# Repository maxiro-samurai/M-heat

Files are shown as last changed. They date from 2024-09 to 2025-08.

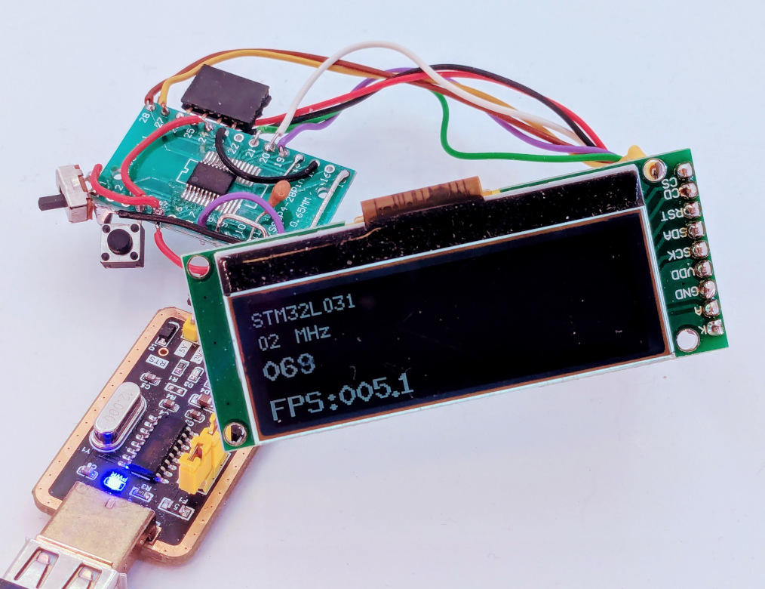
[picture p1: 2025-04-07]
Software/esp32/components/u8g2/sys/arm/stm32l031x4/u8g2_dma_spi_2mhz/stm32l031_wired.jpg

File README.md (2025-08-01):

# M-heat 迷你加热台项目

焊接电路使用电烙铁太麻烦了，尤其遇到0402、QFN这种封装的很难受，想做一个加热板并且还要够mini。本次项目主要参考了 

* 找羊大佬 [加热台量产计划](https://oshwhub.com/sheep_finder/pcb-heng-wen-jia-re-tai)

* 小O和小Q [[PD协议 | 高颜值]mini加热台](https://oshwhub.com/littleoandlittleq/bian-xie-jia-re-tai)

* 稚晖君 [OpenHeat] (https://github.com/peng-zhihui/OpenHeat)

# 项目介绍

主要结构部分采用mini加热台整体框架，外壳自己重新设计。OLED屏幕换成更大一点的128*64，主控芯片采用ESP32，不使用外接电源只需要一根TYPE-C，功率为65W。UI界面使用[oled-ui-astra-lite](https://github.com/AstraThreshold/oled-ui-astra-lite)，感谢无理造物大佬开源，这位大佬的项目也很有意思。

使用编码器与thingsboard来控制加热台，可以实现温度设定、PID参数整定、监测加热器状态等功能，最高温度250°，符合一般中低温锡膏使用情形。源项目中还有初次上电温度校准功能，目前并未添加。

## 未加外壳




## 整体装配
control_board-v20


## 加热板
加热板使用希尔伯特曲线填充， 希尔伯特曲线是一种能在 2D平面完美填充正方形的曲线，连续且稳定（当细分足够小时，线构成面）而又不可导的曲线。只要恰当选择函数，画出一条连续的参数曲线，当参数 t 在 [0、1 ] 区间取值时，曲线将遍历单位正方形中所有的点，得到一条充满空间的曲线。

阻值计算公式为：$R = \frac{\rho L}{1000W \cdot D}$

ρ为铜的电阻率：ρ=0.0175 $\frac{\Omega\cdot mm^2}{m}$

L为走线长度：单位(m)

W为走线宽度：单位(m)

D为PCB铜厚度：1oz 覆铜板铜箔的厚度是0.035mm

取 L=0.4mm（即单位长度），W=0.2mm，可以估算Hilbert 曲线在不同阶数下等效的PCB电阻。
本设计中导线电阻约等于6.67 Ω。

加热板使用铝基板打样


## PID参数整定

P值与I值尽量不要太大，这个版本没有风扇，所以降温比较慢，P值和I值过大会导致超调很多并且很慢恢复。

# 开发记录
* 2024/9/12   目前正在打板验证，本次提交是创建项目仓库。

* 2024/9/14   电源部分设计有问题，DC-DC降压模块稳定工作需要一定压降，TPS5430和MP1584EN输入5V输出必须比5V低。准备更改电源方案，输入转3.3V，3.3V再升压得到5V。

* 2024/11/19  近期在完善打印机，准备加快速度完成本项目，之前电路已经更改暂时未打板验证。

* 2024/12/3   更改电路踩坑记录: 1.type-c母座不要虚焊，cc1 cc2引脚可以不用下拉电阻，ch224k芯片内部已经内置下拉5.1K电阻。2.ch224k芯片背部GND焊盘一定要焊上，不然诱导不出来20V电压。3.充电器一定要用带支持PD20V协议的，一开始诱导不出来后面换了个充电头就可以诱导出来了。4.LM358引脚一定要看好，在找羊原项目里按照原理图画的8脚跟4脚搞反了，8脚是电源正。5.ESP32下载电路有问题，插上type-c后电脑可以识别CH340芯片，用示波器看EN跟BOOT0引脚也有跳变，就是波形可能不符合上电顺序导致无法进入下载程序模式，参考别人设计后发现他们en引脚都上拉电阻并且连了一个电容做延时，所以电路还需要继续完善。6.蜂鸣器封装需要更换。

* 2025/4/14   快开始找工作了，加快项目进度，之前电路修改部分已完成。软件部分把UI、蜂鸣器、编码器、已经移植。目前正在调试ADC测温电路，没有搞清原项目中的测温原理。

    
原理：分高温和低温，因为高温NTC电阻测温精度较差，低温精度还行。低温直接使用，高温下对电压放大21倍后使用线性插值方法对误差进行补偿。

* 2025/4/22   想到后面调PID每次都需要重新下载烧录代码很麻烦，所以想到用野火的串口助手，里面有调试PID的功能。但是需要满足野火通信的协议，参考[踏雪Vernon](https://github.com/taxue-vernon/firetool_PID_driver_esp)大佬的代码把功能移植到本项目中。当前面临问题：只有串口0能用，串口0还是下载程序的串口，软件把下载串口占用导致无法下载程序，我在改进后的板子上在EN引脚上添加了一个复位按键，理论上来说可以下载程序。担心是多余的，自动下载电路中有硬件流控，能使ESP32自动复位进入bootloader。软件部分还需要增加保存PID、温度、时间等一些温度的设置功能，这就需要非易失存储器保存数据，比如eeprom。这里使用ESP32中的NVS来存储，详情看[ESP32 非易失性存储器NVS](https://docs.espressif.com/projects/esp-idf/zh_CN/v5.4.1/esp32s3/api-reference/storage/nvs_flash.html#id2)。还忽略了一点，如果使用野火串口助手则无法开启加热功能，因为电脑端USB口无法输出65W。最终调试PID还是没用到串口助手，而是使用WIFI网页控制进行调试，如果想使用串口可以多引出一个串口1用来调试。

* 2025/5/14   使用[thingsboard](https://github.com/thingsboard/thingsboard)开源物联网框架搭建服务器，实现在网页端显示温度，PID参数并且对设备进行控制。

    

* 2025/5/23  基本功能已经开发完毕，后续还需添加蓝牙通信功能（使用手机进行控制）、更完善的加热状态判断。结构后续也可完善，在200°温度下，由顶针连接控制板导致控制板温度也很高，这个问题在原mini加热台项目中应该也存在，3D打印的外壳与加热板离得很近，长时间使用可能会有问题。加热板也可做沉孔，目前版本中并未做沉孔。

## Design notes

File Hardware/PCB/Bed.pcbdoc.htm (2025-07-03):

Reporting Options

# File in Newer Format

Date | : | 2025/7/3
Time | : | 9:25:11
Filename | : | D:\project\M-heat\Hardware\PCB\Bed.pcbdoc

Version | Warning
6.3 | CAUTION - Via connections to both hatched and solid signal layer polygons are now controlled by the polygon connect style rule. Re-pouring polygons may result in physical copper differences.
Summer 09 | CAUTION - File contains old violation objects. These violations are no longer supported & will not be loaded. Please run DRC after opening this file in order to refresh the violations.
Summer 09 | CAUTION - Existing testpoint rules and settings are used as fabrication testpoint information.
Release 12 | CAUTION - Air Gap Width previously controlled by Clearance rule is now controlled by Polygon Connect Style rule's newly introduced Air Gap Width (set to default value). Suggest reviewing each Polygon Connect Style rule's Air Gap Width attribute for correctness.
Release 13 | CAUTION - Silkscreen Over Component Pads Rules are converted to Silk To Solder Mask Clearance Rules. Suggest examining rule scopes for accuracy.

This file was generated by an earlier version of the software

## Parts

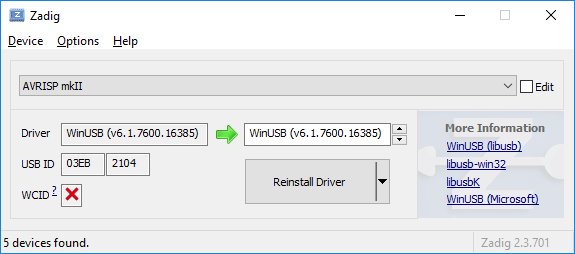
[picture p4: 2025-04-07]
Software/esp32/components/u8g2/sys/avr/as7/as7_011.png

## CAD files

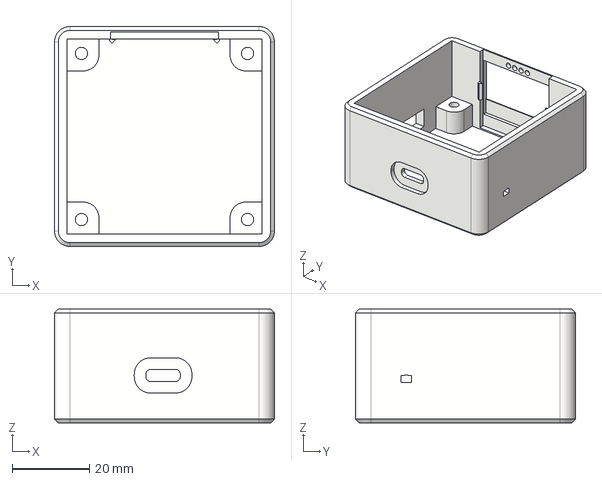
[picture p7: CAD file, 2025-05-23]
Hardware/3DFile/外壳.step
57.0 x 57.0 x 29.5 mm

Software/esp32/components/u8g2/sys/arduino/u8g2_full_buffer/SwitchBox/board.dxf
60
40
52
8
24
80
30
32
25
100
190
4
12
6
14

Software/esp32/components/u8g2/sys/arm/stm32l031x6/clock.dxf
65
32
28
16
Draufsicht
Vorderansicht
von unten
von rechts
von links
14
6
45
60
30
20
8
35
75
55
10
12

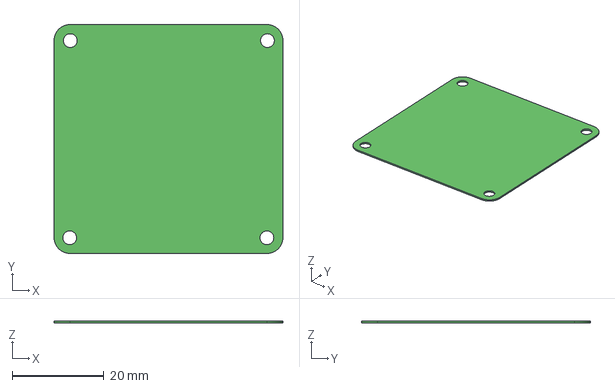
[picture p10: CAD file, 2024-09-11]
Hardware/3DFile/Bed.step
50.0 x 50.0 x 0.411 mm

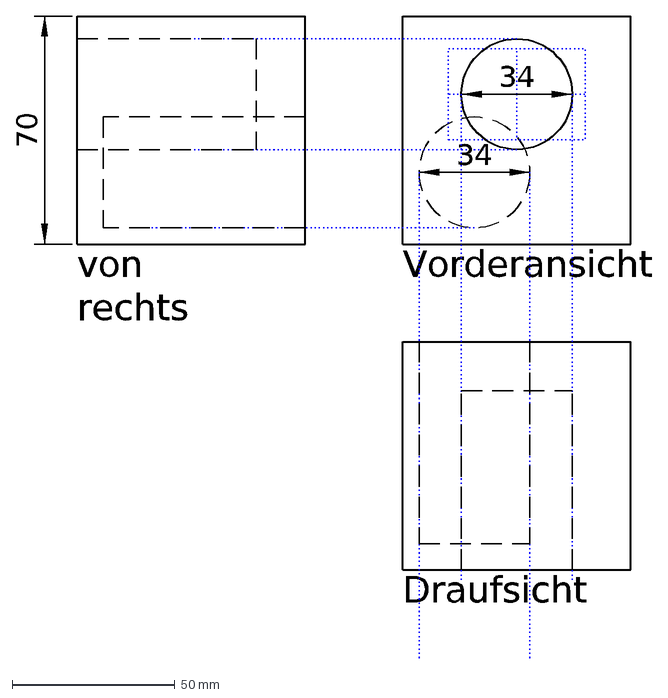
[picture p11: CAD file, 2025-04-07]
Software/esp32/components/u8g2/sys/arm/stm32l031x6/clock_cube.dxf
Draufsicht
Vorderansicht
von rechts
70
34

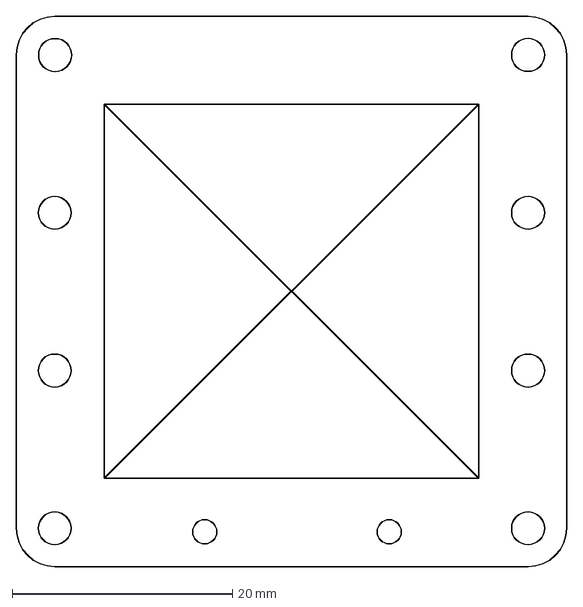
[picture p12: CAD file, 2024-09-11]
Hardware/3DFile/隔热板.dxf
50.0 x 50.0 mm

Software/esp32/components/u8g2/sys/arm/stm32l031x6/clock_2.dxf
65
Draufsicht
Vorderansicht
von unten
von rechts
von links
14
30
32
35
75
55
10
12
16
11
22
34
28
29
18
93
19
43
15
68
60
57
150
Holzbohrer: 2.5, 8, 10, 12, 16, 32mm
8
7
6
2.5mm

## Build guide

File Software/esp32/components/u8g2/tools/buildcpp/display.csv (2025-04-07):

# 1. device name
# 2. pinset
# 3. constructor name w/o prefix
u8x8_d_ssd1306_128x64_noname | 4WSWSPI | SSD1306_128X64_4W_SW_SPI
u8x8_d_ssd1306_128x64_noname | 4WHWSPI | SSD1306_128X64_4W_HW_SPI
u8x8_d_ssd1306_128x64_noname | 3WSWSPI | SSD1306_128X64_3W_SW_SPI
u8x8_d_ssd1306_128x64_noname | SSDSWI2C | SSD1306_128X64_SW_I2C
u8x8_d_ssd1306_128x64_noname | 6800 | SSD1306_128X64_6800
u8x8_d_ssd1306_128x64_noname | 8080 | SSD1306_128X64_8080

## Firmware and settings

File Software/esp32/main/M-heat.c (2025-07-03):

#include "M-heat.h"


bool wifi_enable = false;
bool ble_state = false;


void app_main(void) {
  rotary_encoder_init();//旋转编码器初始化
  beep_init();//蜂鸣器初始化
  beep_test(&BootSound); // 声音也有点奇怪
  astra_ui_driver_init(); //初始化I2C驱动
  astra_init_core(); //初始化UI核心
  heater_init(); //初始化加热器
  nvs_init(); //初始化NVS
  nvs_get_parameter("Kp",&pid.Kp);
  nvs_get_parameter("Ki",&pid.Ki);
  nvs_get_parameter("Kd",&pid.Kd);
  wifi_init_sta();
  // // 设置时区并启动 SNTP
  // set_timezone();
  // initialize_sntp();
  // // 等待时间同步完成
  // wait_for_time_sync();
  UI_init();
  // 等待 Wi-Fi 连接成功
  vTaskDelay(2000 / portTICK_PERIOD_MS);
  

  
  BaseType_t xReturned = xTaskCreate(UI_task, "UI_task", 8192, NULL, 4, NULL);
  if(xReturned == pdPASS) {
    ESP_LOGI("Task", "UI_task created successfully");
  } else {
    ESP_LOGE("Task", "Failed to create UI_task");
  }
  xReturned = xTaskCreate(encoder_task, "encoder_task", 2048, &rotatry_encoder, 5, NULL);
  if(xReturned == pdPASS) {
    ESP_LOGI("Task", "encoder_task created successfully");
  } else {
    ESP_LOGE("Task", "Failed to create encoder_task");
  }

  xReturned = xTaskCreate(adc_oneshot_read_task, "adc_oneshot_read_task", 2048, NULL, 2, NULL);

  xTaskCreate(Temperature_Control_task, "Temperature_Control_task", 2048, NULL, 3, NULL);

  xTaskCreate(http_long_poll_task, "http_long_poll_task", 8192, NULL, 4, NULL);


}

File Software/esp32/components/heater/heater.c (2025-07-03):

#include "heater.h"

uint8_t sample_time_list[3]={200,100,50};//采样时间列表
gptimer_handle_t gptimer = NULL;  
QueueHandle_t queue = NULL;
bool PWMOutput_Lock = false;

static const char *TAG = "PID";
bool PWM_state = true;

/**
 * * @brief 定时器中断回调函数
 * * * @param timer 定时器句柄
 * * * @param edata 定时器事件数据
 * * * @param user_data 用户数据(一般用作传递队列句柄)
 * * * @return true: 需要在ISR结束时切换上下文，false: 不需要
 */
static bool IRAM_ATTR timer_on_alarm_cb(gptimer_handle_t timer, const gptimer_alarm_event_data_t *edata, void *user_data)

{
    static event_sign_t event_sign ;
    event_sign_t *event_sign_ptr = &event_sign;
    BaseType_t high_task_awoken = pdFALSE;
    QueueHandle_t queue = (QueueHandle_t)user_data;
    event_sign.alarm_value = edata->alarm_value; // 获取定时器触发值
    event_sign.pid_sample_count++;
    // 中断函数尽量不要写太多的代码，避免影响中断响应时间
    // 这里我们只是将定时器的触发值发送到队列中，用来计算定时器间隔
    xQueueSendFromISR(queue, &event_sign_ptr, &high_task_awoken);
    // return whether we need to yield at the end of ISR
    return (high_task_awoken == pdTRUE);
}
void heater_stop(void){

    ledc_stop(LEDC_LOW_SPEED_MODE, HEATER_ChANNEL, 0);  // 停止加热
}

/** 
    * @brief 初始化串口
    * @param pwm 占空比值，范围0-8191  (13位分辨率)
    * @note 该函数用于设置加热器的PWM输出值，范围为0-8191（13位分辨率）。
    */
 void heater_output(uint16_t pwm)
{
    if(PWMOutput_Lock)
    pwm = 0;
    ledc_set_duty(LEDC_LOW_SPEED_MODE, HEATER_ChANNEL, pwm);
    ledc_update_duty(LEDC_LOW_SPEED_MODE, HEATER_ChANNEL);

}

/** 
    * @brief PID控制器初始化函数
    * @param pid PID控制器结构体指针
    * @param Kp 比例系数
    * @param Ki 积分系数    
    * @param Kd 微分系数
    * @param output_min 输出最小值（限幅）
    * @param output_max 输出最大值（限幅）
    * @param Sample_time 采样时间（ms）
    * @note 该函数用于初始化PID控制器的参数。
    */
static void pid_init(pid_controller_t *pid, float Kp, float Ki, float Kd, float output_min, float output_max,uint32_t Sample_time )
{
    pid->Kp = Kp;
    pid->Ki = Ki;
    pid->Kd = Kd;
    pid->integral = 0.0f;
    pid->prev_error = 0.0f;
    pid->output_min = output_min;
    pid->output_max = output_max;
    pid->Sample_time = Sample_time; // 单位为ms

    /*设置时间间隔,即设置报警计数器*/
    timer_set_alarm(gptimer,(uint64_t)Sample_time*1000);
}

/**
 * * @brief 设置PID参数
 * * @param pid PID控制器结构体指针
 * * @param Kp 比例系数
 * * @param Ki 积分系数
 * * @param Kd 微分系数
 * * @note 该函数用于设置PID控制器的参数。
 */
void pid_set_param(pid_controller_t *pid, float Kp, float Ki, float Kd)
{

    if(pid->Kp != Kp){
        pid->Kp = Kp;
    }else if (pid->Ki != Ki) {
        pid->Ki = Ki;
    }else if ( pid->Ki != Ki) {
    
        pid->Ki = Ki;
        
    }
    
    
}
/** 
 *  @brief 设置采样时间
 *  @param pid PID控制器结构体指针
 *  @param Sample_time 采样时间（ms）
 * *  @note 该函数用于设置PID控制器的采样时间。
 */
void pid_set_sample_time(pid_controller_t *pid, uint32_t Sample_time)
{
    static uint32_t last_sample_time;

    pid->Sample_time = Sample_time;
    
    if (last_sample_time != Sample_time)
    timer_set_alarm(gptimer,(uint64_t)Sample_time*1000);


    last_sample_time = Sample_time; 

}

/**
 * @brief 设置输出限幅
 * @param pid PID控制器结构体指针
 * @param output_min 输出最小值（限幅）
 * @param output_max 输出最大值（限幅）
 * @note 该函数用于设置PID控制器的输出限幅。
 */
void pid_set_output_limits(pid_controller_t *pid, float output_min, float output_max)
{
    pid->output_min = output_min;
    pid->output_max = output_max;
}
/**
 * @brief 计算PID控制器输出值
 * @param pid PID控制器结构体指针
 * @param setpoint 设定值
 * @param measured_value 测量值
 * @return PID控制器输出值
 * @note 该函数用于计算PID控制器的输出值。
 */
uint16_t pid_calculate(pid_controller_t *pid, float setpoint, float measured_value)
{
    // 计算误差
    float error = setpoint - measured_value;
    // 计算积分项
   
    float SampleTimeInSeconds = pid->Sample_time / 1000.0; // Convert milliseconds to seconds

    // 计算积分项
    pid->integral += error * SampleTimeInSeconds; 
    // 限幅处理
    if (pid->integral > pid->output_max) {
        pid->integral = pid->output_max;
    } else if (pid->integral < pid->output_min) {
        pid->integral = pid->output_min;
    }

    // 计算微分项
    float derivative = (error - pid->prev_error) / SampleTimeInSeconds;
    // 计算输出值
    float output = (pid->Kp * error) + (pid->Ki * pid->integral) + (pid->Kd * derivative);
    // 限幅处理
    if (output > pid->output_max) {
        output = pid->output_max;
    } else if (output < pid->output_min) {
        output = pid->output_min;
    }
    // 更新上一次误差
    pid->prev_error = error;
    
    return (uint16_t)(output);


}
/** 
 * * @brief 设置目标值
 * * @param pid PID控制器结构体指针
 * * @param target_value 目标值
 * * @note 该函数用于设置PID控制器的目标值。
 */
void pid_set_target_value(pid_controller_t *pid, float target_value)
{
    pid->target_value = target_value;
}

void heater_init(void)
{
    /*PWM驱动初始化*/
 // Prepare and then apply the LEDC PWM timer configuration
    ledc_timer_config_t heater_timer = {
        .speed_mode       = LEDC_LOW_SPEED_MODE,
        .timer_num        = HEATER_TIMER,
        .duty_resolution  = LEDC_TIMER_13_BIT,
        .freq_hz          = HEATER_FREQUENCY,  // Set output frequency at 5 kHz
        .clk_cfg          = LEDC_AUTO_CLK
    };
    ESP_ERROR_CHECK(ledc_timer_config(&heater_timer));

    // Prepare and then apply the LEDC PWM channel configuration
    ledc_channel_config_t heater_channel = {
        .speed_mode     = LEDC_LOW_SPEED_MODE,
        .channel        = HEATER_ChANNEL,
        .timer_sel      = HEATER_TIMER,
        .intr_type      = LEDC_INTR_DISABLE,
        .gpio_num       = HEATER_OUTPUT_IO,
        .duty           = 0, // Set duty to 0%
        .hpoint         = 0
    };
    ESP_ERROR_CHECK(ledc_channel_config(&heater_channel));
    ledc_stop(LEDC_LOW_SPEED_MODE, HEATER_ChANNEL, 0);  // 停止加热


    /*初始化定时器，用于PID采样*/
    queue = xQueueCreate(5, sizeof(void*)); // 创建队列，用于接收定时器事件
    gptimer_config_t timer_config = {
        .clk_src = GPTIMER_CLK_SRC_DEFAULT,
        .direction = GPTIMER_COUNT_UP,
        .resolution_hz = 1000000, // 1MHz, 1 tick=1us
    };

    ESP_ERROR_CHECK(gptimer_new_timer(&timer_config, &gptimer));

    gptimer_event_callbacks_t cbs = {
        .on_alarm = timer_on_alarm_cb,
    };

    ESP_ERROR_CHECK(gptimer_register_event_callbacks(gptimer, &cbs, queue));

    gptimer_alarm_config_t alarm_config = {
        .alarm_count =1000, // period = 1ms
        .reload_count = 0,
        .flags.auto_reload_on_alarm = true,
    };

    ESP_ERROR_CHECK(gptimer_set_alarm_action(gptimer, &alarm_config));
    ESP_ERROR_CHECK(gptimer_enable(gptimer));
    ESP_ERROR_CHECK(gptimer_start(gptimer));
}

bool en_pid= true;
uint16_t output_pwm;


// FireToolPIDAdaptor fireToolPidAdaptor;
// /**野火PID调试助手 */
// void fta_start_callback(unsigned char channel)
// {
//     printf("start command!,channel: %d\n", channel);
// }

// void fta_stop_callback(unsigned char channel)
// {
//     printf("stop command!channel: %d\n", channel);
// }

// void fta_reset_callback(unsigned char channel)
// {
//     printf("reset command!channel: %d\n", channel);
// }
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

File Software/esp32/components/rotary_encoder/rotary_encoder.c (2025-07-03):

/*
 * SPDX-FileCopyrightText: 2010-2022 Espressif Systems (Shanghai) CO LTD
 *
 * SPDX-License-Identifier: CC0-1.0
 */

#include "rotary_encoder.h"
 
static const char *TAG = "example";
QueueHandle_t encoder_queue = NULL;
QueueHandle_t buton_queue = NULL;
pcnt_unit_handle_t pcnt_unit = NULL;

rotary_encoder_item_t rotatry_encoder = {
    .en_torary = false, //禁用旋转编码器
    .key_state = IDLE,
    .encoder_state = IDLE_ENCODER,
    .last_tick = 0,
    .last_encoder_value = 0,
    .encoder_value = 0,
    .hold_tick = 0,
    .press_start =0,
    .last_key_state = IDLE,
};
// rotary_encoder_item_t rotatry_encoder = {};

static bool example_pcnt_on_reach(pcnt_unit_handle_t unit, const pcnt_watch_event_data_t *edata, void *user_ctx)
 {
     BaseType_t high_task_wakeup;
     QueueHandle_t queue = (QueueHandle_t)user_ctx;
     // send event data to queue, from this interrupt callback
     // ESP_LOGI(TAG, "Watch point event, count: %d", edata->watch_point_value);
     xQueueSendFromISR(queue, &(edata->watch_point_value), &high_task_wakeup);
     pcnt_unit_clear_count(pcnt_unit); //达到计数最大/小值清零
     return (high_task_wakeup == pdTRUE);
 }
 
 // 按键中断处理（可选）
 static void IRAM_ATTR Key_isr(void* arg) {
    static uint32_t last_press = 0;
    uint32_t now = xTaskGetTickCountFromISR();

    // 消抖处理（200ms内不重复触发）
    if (now - last_press < pdMS_TO_TICKS(100)) return;
    last_press = now;

    // 发送按键事件到队列
    int8_t btn_event = 0;
    xQueueSendFromISR(buton_queue, &btn_event, NULL);
}



static void pcnt_init(void)
{
    ESP_LOGI(TAG, "install pcnt unit");
     pcnt_unit_config_t unit_config = {
         .high_limit = EXAMPLE_PCNT_HIGH_LIMIT,
         .low_limit = EXAMPLE_PCNT_LOW_LIMIT,
     };
     
     ESP_ERROR_CHECK(pcnt_new_unit(&unit_config, &pcnt_unit)); //新建pcnt单元
 
     ESP_LOGI(TAG, "set glitch filter");
     pcnt_glitch_filter_config_t filter_config = {
         .max_glitch_ns = 10000,
     };
     ESP_ERROR_CHECK(pcnt_unit_set_glitch_filter(pcnt_unit, &filter_config)); //滤波器配置
 
     ESP_LOGI(TAG, "install pcnt channels");
     pcnt_chan_config_t chan_a_config = {
         .edge_gpio_num = EXAMPLE_EC11_GPIO_A,
         .level_gpio_num = EXAMPLE_EC11_GPIO_B,
     };
     pcnt_channel_handle_t pcnt_chan_a = NULL;
     ESP_ERROR_CHECK(pcnt_new_channel(pcnt_unit, &chan_a_config, &pcnt_chan_a));//A通道配置
     pcnt_chan_config_t chan_b_config = {
         .edge_gpio_num = EXAMPLE_EC11_GPIO_B,
         .level_gpio_num = EXAMPLE_EC11_GPIO_A,
     };
     pcnt_channel_handle_t pcnt_chan_b = NULL;
     ESP_ERROR_CHECK(pcnt_new_channel(pcnt_unit, &chan_b_config, &pcnt_chan_b));//B通道配置
 
     ESP_LOGI(TAG, "set edge and level actions for pcnt channels");
     ESP_ERROR_CHECK(pcnt_channel_set_edge_action(pcnt_chan_a, PCNT_CHANNEL_EDGE_ACTION_DECREASE, PCNT_CHANNEL_EDGE_ACTION_INCREASE));
     ESP_ERROR_CHECK(pcnt_channel_set_level_action(pcnt_chan_a, PCNT_CHANNEL_LEVEL_ACTION_KEEP, PCNT_CHANNEL_LEVEL_ACTION_INVERSE));
     ESP_ERROR_CHECK(pcnt_channel_set_edge_action(pcnt_chan_b, PCNT_CHANNEL_EDGE_ACTION_INCREASE, PCNT_CHANNEL_EDGE_ACTION_DECREASE));
     ESP_ERROR_CHECK(pcnt_channel_set_level_action(pcnt_chan_b, PCNT_CHANNEL_LEVEL_ACTION_KEEP, PCNT_CHANNEL_LEVEL_ACTION_INVERSE));
 
     ESP_LOGI(TAG, "add watch points and register callbacks");
     int watch_points[] = {EXAMPLE_PCNT_LOW_LIMIT, EXAMPLE_PCNT_HIGH_LIMIT};
     for (size_t i = 0; i < sizeof(watch_points) / sizeof(watch_points[0]); i++) {
         ESP_ERROR_CHECK(pcnt_unit_add_watch_point(pcnt_unit, watch_points[i]));
     }
     pcnt_event_callbacks_t cbs = {
         .on_reach = example_pcnt_on_reach,
     };


     encoder_queue = xQueueCreate(10, sizeof(int16_t));
    

     ESP_ERROR_CHECK(pcnt_unit_register_event_callbacks(pcnt_unit, &cbs, encoder_queue));
 
     ESP_LOGI(TAG, "enable pcnt unit");
     ESP_ERROR_CHECK(pcnt_unit_enable(pcnt_unit));
     ESP_LOGI(TAG, "clear pcnt unit");
     ESP_ERROR_CHECK(pcnt_unit_clear_count(pcnt_unit));
     ESP_LOGI(TAG, "start pcnt unit");
     ESP_ERROR_CHECK(pcnt_unit_start(pcnt_unit));
}

static void Key_init(void)
{
    ESP_LOGI(TAG, "install GPIO interrupt");
    gpio_config_t io_conf = {
        .pin_bit_mask = 1ULL <<EXAMPLE_KEY_GPIO,
        .mode = GPIO_MODE_INPUT,
        .pull_up_en = GPIO_PULLUP_ENABLE,
        .pull_down_en = GPIO_PULLDOWN_DISABLE,
        .intr_type = GPIO_INTR_ANYEDGE
    };
    ESP_ERROR_CHECK(gpio_config(&io_conf));
    
    ESP_LOGI(TAG, "install GPIO interrupt");
    buton_queue = xQueueCreate(10, sizeof(int8_t));
    ESP_ERROR_CHECK(gpio_install_isr_service(0));
    ESP_ERROR_CHECK(gpio_isr_handler_add(EXAMPLE_KEY_GPIO, Key_isr, (void*)EXAMPLE_KEY_GPIO));
    

}

void rotary_encoder_init(void)
{
    pcnt_init();
    Key_init();
}

/*

@ 编码器状态扫描

*/

void encoder_state_detection(rotary_encoder_item_t *encoder) {
   
    // static int16_t last_encoder_val = 0; //上一次读取到的值
    // static int32_t last_tick = 0; //上次读取时间
    // static ButtonState button_state = IDLE; // 按键状态

    // int16_t encoder_val = 0; 

    pcnt_unit_get_count(pcnt_unit,&encoder->encoder_value); //读取编码器值
    
    
    
    
    // ESP_LOGI(TAG, "系统时间: %lu ms", current_tick);
    
    // 处理旋转方向
    if (encoder->encoder_value != encoder->last_encoder_value) {
        if (encoder->encoder_value > encoder->last_encoder_value + 3) {
            ESP_LOGI(TAG, "编码器左旋转,值: %d", encoder->encoder_value);
            encoder->encoder_state = LEFT;
            beep_test(&Beep1);
        } else if(encoder->encoder_value < encoder->last_encoder_value - 3) {
            ESP_LOGI(TAG, "编码器右旋转,值: %d", encoder->encoder_value);
            encoder->encoder_state = RIGHT;
            beep_test(&Beep1);
        }
        encoder->last_encoder_value = encoder->encoder_value; 
        
        

    } else {
        // ESP_LOGI(TAG, "编码器未动作");
        encoder->encoder_state = IDLE_ENCODER; // 编码器未动作
    }
   
}

void encoder_key_detection(rotary_encoder_item_t *encoder){
int GPIO_LEVEL ; //读取GPIO电平
GPIO_LEVEL = gpio_get_level(EXAMPLE_KEY_GPIO);
uint32_t current_tick = xTaskGetTickCount() * portTICK_PERIOD_MS;  //获取当前时间

// if (xQueueReceive(buton_queue, &GPIO_LEVEL, 0) == pdTRUE) { 
//     //读取按键事件
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

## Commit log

2024-09-11 创建新项目
    [Bed.pcbdoc, Bed.step, M-heat.PrjPcb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]
2024-11-18 更改电源电路
    [M-heat.PrjPcb, Sheet1.SchDoc]
2024-12-03 验证完善电路
2024-12-03 添加图片
2024-12-03 踩坑记录
2024-12-03 更改电路，添加西电标志
2024-12-03 更改电路
    [Sheet1.SchDoc]
2025-04-05 最小系统验证，准备软件框架
2025-04-07 添加u8g2库，驱动屏幕
    [board.dxf, clock.dxf, clock_2.dxf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]
2025-04-07 添加主程序测试
2025-04-07 .csv 例程复制
    [partitions_example.csv]
2025-04-08 调试astra UI,底层驱动移植完毕
    [partitions_example.csv]
2025-04-08 添加忽略的文件
2025-04-08 删除配置，输出文件
2025-04-08 list内存访问问题
2025-04-10 astra UI 界面已经调试成功
2025-04-12 增加编码器按键
2025-04-12 添加编码器与UI交互
2025-04-13 添加蜂鸣器驱动
2025-04-13 添加测温模块
2025-04-13 更改屏幕驱动
2025-04-14 更改ADC驱动，已实现读取温度
2025-04-14 更新项目日志
2025-04-15 添加绘制UI文件
2025-04-15 画UI主页面
2025-04-18 编码器优化，增加长按退出功能
2025-04-18 增加画温度曲线功能，UI过度还需要更改
2025-04-21 添加MOS驱动
2025-04-21 长按区分主页界面和UI
2025-04-21 颜色问题，改为先写字体颜色再写底色
2025-04-21 UI主界面更改
2025-04-21 添加野火PID上位机调试协议，以便后面调试PID
2025-04-21 添加PID算法
2025-04-21 增加弹窗
2025-04-22 更新进度
2025-04-24 增加NVS存储模块
2025-04-24 增加timer定时器
2025-04-24 添加注释
2025-04-24 测试添加定时器代替Freertos延时
2025-04-26 测试野火串口助手
2025-04-27 添加电源电压监测
2025-04-27 改善蜂鸣器代码
2025-05-01 添加wifi驱动，测试PID加热
2025-05-06 添加连接thingsboard模块
2025-05-06 更改网址为本地IP，localhost无法访问
2025-05-13 更改主文件名
2025-05-13 增加WIFI网页控制端功能
2025-05-14 添加保存配置
2025-05-14 更新readme
2025-05-22 功能完善，添加加热逻辑判断
2025-05-23 更新外壳文件
    [外壳.step]
2025-05-23 更新readme文件
2025-07-03 更新readme文档
2025-07-03 一些调试更改
2025-07-03 更新文档
